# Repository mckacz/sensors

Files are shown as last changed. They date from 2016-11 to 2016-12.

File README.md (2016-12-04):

Simple wireless sensor system
=============================

As a part of home automation system for my house, I have designed a wireless sensors system that can continuously
monitor temperature, humidity, light and atmospheric pressure of multiple spots in the building.

This repository contains all elements required to build your own wireless sensor system based on ATmega328P, 
Raspberry PI and NRF24L01:

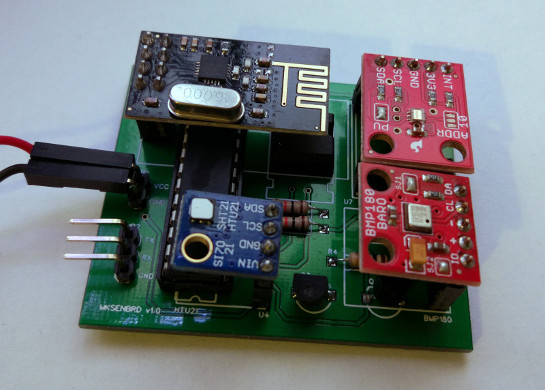
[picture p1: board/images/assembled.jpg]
Wireless sensor module


| Directory | Description |
|---|---|
| [board](./board) | Schematic and PCB design of wireless sensor module |
| [firmware](./firmware) | Arduino-compatible firmware for wireless sensor module |
| [example-server](./example-server) | Simple wireless sensors server for Raspberry PI | 

Case study
----------

As I mentioned, this wireless sensor system is a part of home automation system for my house.
At the moment, I have five wireless sensors connected to it. Each sensor module sends new readings in 16 seconds 
intervals and is powered by 3xAA rechargeable batteries - it is enough to power the module for over **2 months**. 
Power consumption is **~0.05 mA** in sleep mode and **20-30 mA** while measurements.  

**Cost of single module**

| Item | Price  | Note |
|---|---|---|
| PCB | $0.88  | ... if you order 20 PCB from EasyEDA (does not include shipping cost) |
| ATmega328P | $1.23* | |
| LD1117AV33 | $0.35* | |
| NRF24L01+ | $0.75* | |
| HTU21D | $2.40* | |
| TSL2561 | $1.50* | |
| BMP180 | $2.20* | |
| Other parts | $0.50* | Resistors, transistor, sockets |

Fully featured version: **$9.81**  
Temperature + humidity + light: **$7.61**  
Temperature + humidity: **$6.11**

Sums do not include cost of power supply. 

*) Prices from aliexpress.com (2016-12-04).

License
-------

[MIT](./LICENSE)

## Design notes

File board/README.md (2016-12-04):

Wireless sensor module board
============================

This directory contains schematic and PCB design for single wireless sensor module in [EAGLE](https://cadsoft.io/) 
format. Board design is also available on [EasyEDA](https://easyeda.com/maciej/sensors-387a7c4150d841bbb06d5350ea664e67).  

**Features**:
 * small dimensions - 55x45mm
 * low power consumption - ~40mA during measurement and ~40µA (0.04mA) in standby
 * supports standard BMP180, HTU21D and TSL2561 breakout boards - min. one is required, but all can be installed at same time 
 * input voltage from 3 to 5.5V 
 * low cost
 * open source [firmware](../firmware) 

Part list
---------

| PCB ID | Part name | Qty | Description |
|---|---|-----|---|
| U1 | ATmega328P (DIL28) |  1  | microcontroller |
| U2 | LD1117AV33 (TO220) |  1  | voltage regulator |
| U3 | NRF24L01+ |  1  | radio module |
| U4 | HTU21D (breakboard)  |  1  | temperature and humidity sensor | 
| U5/U6* | TSL2561 (breakboard) |  1  | luminescence sensor | 
| U7 | BMP180 (breakboard)  |  1  | barometer sensor |
| R1, R2 | resistor 10k |  2  | resistor |
| Q1 | BC337-40 |  1  | NPN transistor | 
| | pinhead 1x2 |  1  | pin header connector | 
| | pinhead 1x3 |  1  | pin header connector | 
| | pinhead 1x4 |  1  | pin header connector | 
| | pinhead 2x4 |  1  | pin header connector | 
| | pinhead 1x5 |  3  | pin header connector | 
| | DIL28 socket |  1  | socket for ATmega328P | 

*) There are two TSL2561 connectors (with different pin order) on the board, 
   but only one TSL2561 can be used at same time. 
 
Top layer
---------

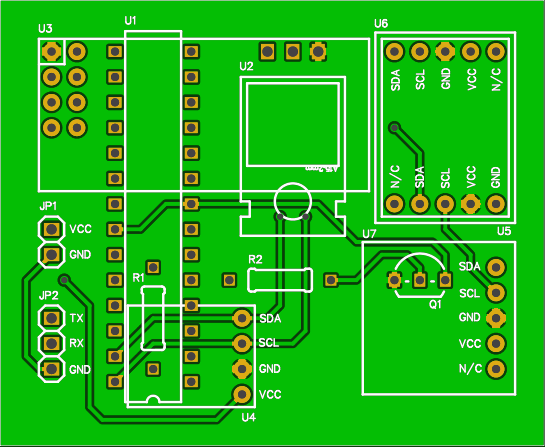
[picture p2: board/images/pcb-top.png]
Top layer


Bottom layer
------------

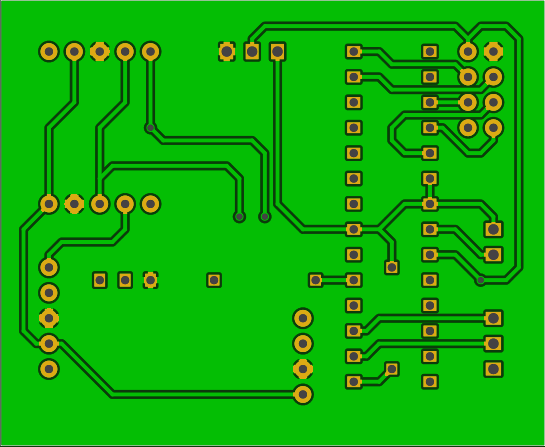
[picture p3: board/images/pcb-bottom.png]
Bottom layer


Assembled board
---------------

Wireless sensor module

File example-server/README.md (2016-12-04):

Example server
--------------

This is example of server that listens for readings send by wireless modules.

**Hardware requirements**

* Raspberry PI with enabled SPI
* NRF24L01+ radio module connected to Raspberry PI
* at least one [wireless sensor module](../board) with proper [firmware](../firmware)

**Software requirements**

* Python 3
* `spidev` package 
* [pyNRF](https://github.com/nettigo/pyNRF)
* [Tornado Web Server](http://www.tornadoweb.org/en/stable/)
* NodeJS and NPM to modify frontend JS files

**Running the example**
1. clone or download this repository
2. edit [`server.py`](./server.py) and set:
 * radio channel (same as option 1 in wireless module setup)
 * radio address (same as option 3 in wireless module setup)
 * your sensor names (key is sensor's ID from option I and value is name that will be displayed for the sensor)
  
3. run `python3 server.py` in `example-server` directory
4. open in a browser `http://your-raspberry-pi-ip:8000`

If everything works, you should see readings from your wireless sensors:
  
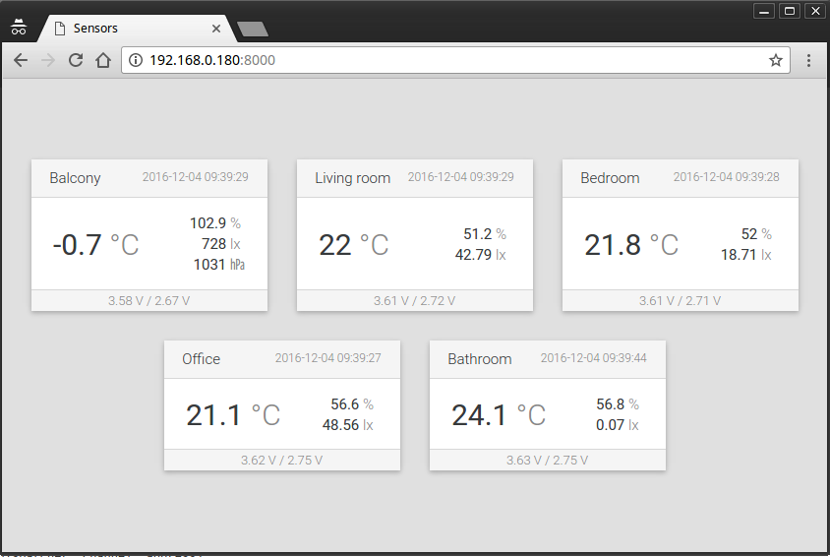
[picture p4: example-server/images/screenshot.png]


Readings on a web page will be updated (thought WebSocket) as soon as new reading will be received by the server.

**Modifying the example**

Example consists of:

* [`server.py`](./server.py) - main file of the server
* [`backand`](./backend) - classes used by the server
* [`frontend`](./frontend) - source JS files of frontend application compiled to `static/app.js` (ES6, React)
* [`static`](./static) - static files used by frontend application (HTML, CSS)

Everything except files in [`frontend`](./frontend) can be modified directly. [`frontend`](./frontend) contains 
ES6 and JSX files, so they must be compiled after modification.
 
Before first compilation, you must install dependencies with `npm install`, than you are able to run:

* `npm run build` to compile frontend files once
* `npm run watch` to continuously compile frontend files after each modification.

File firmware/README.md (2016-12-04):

Wireless sensor module firmware
===============================

**Features**:

* configurable through serial terminal
* optimized for power consumption (deep sleep mode)
* monitors actual voltage values
* compatible with ATmega328P @ 16MHz / 8MHz 
* easy to extend

Requirements
------------

* [Arduino IDE](https://www.arduino.cc/)
* [Sparkfun BMP180 library](https://github.com/sparkfun/BMP180_Breakout)
* [Sparkfun HTU21D library](https://github.com/sparkfun/SparkFun_HTU21D_Breakout_Arduino_Library)
* [Sparkfun TSL2561 library](https://github.com/sparkfun/SparkFun_TSL2561_Arduino_Library)
* "Minimal circuit" hardware configuration from [Arduino website](https://www.arduino.cc/en/Tutorial/ArduinoToBreadboard)*
* chip programmer* (like USBap)
* serial converter* (like USB TTL Serial)

*) Only if you are going to used it with provided PCB board

Installing on ATmega328p 
------------------------

1. prepare ATmega328p chip fused to run at 8Mhz internal oscillator
2. install required libraries through Arduino IDE's library manager 
3. compile and upload sketch to ATmega328p using your favourite chip programmer 
4. put programmed ATmega328p into socket on the board

Configuring the module
----------------------

1. power off the board
2. connect serial converter to JP2 connector on the board
3. setup and open serial connection 
  
  * boud rate: 19200
  * parity: none
  * bits: 8
  * stopbits: 1
  * flow control: none
  * immediate send characters 
  
4. power on the board
5. within next 5 seconds, press any key in serial terminal to enter setup mode

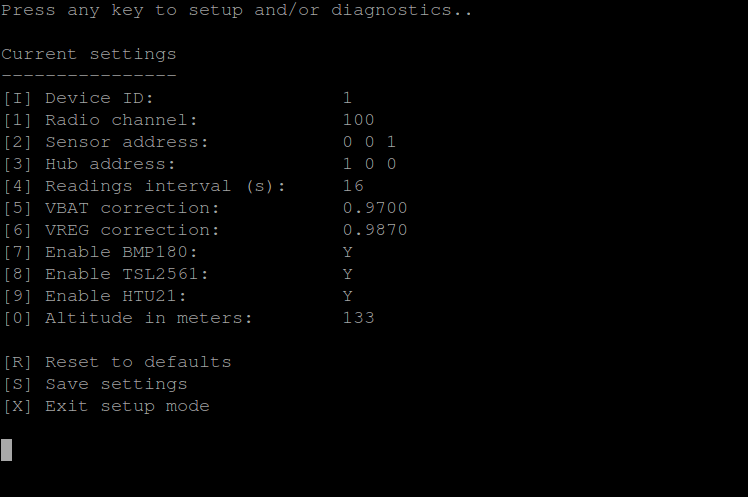
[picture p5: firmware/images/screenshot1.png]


**Available commands**

|  Key  | Description | Expected value | Note |
|---|---|---|---|
| **I** | Set Device ID. The ID will be send to the server with every message. | Integer (0-255) | Value should be unique for every module. |
| **1** | Set radio channel number to communicate with server. | Integer (1-125) | Value should be the same for every module and the server. |
| **2** | Set module radio address that NFR24L01 will use as a source address for each message. | 3x Integer (0-255) | Value should be unique for every module. |
| **3** | Set server radio address that NFR24L01 will use as a destination address for each message. | 3x Integer (0-255) | Value should be the same for every module. |
| **4** | Set reading interval in seconds. | Integer (1-255) | This affects most energy consumption. |
| **5** | Set input voltage reading correction factor. | Float | *factor = (voltage that you measure with multimeter on VCC @ JP1) / (voltage measured by module)*|
| **6** | Set regulated voltage reading correction factor. | Float | *factor = (voltage that you measure with multimeter on VCC @ U4) / (voltage measured by module)* |
| **7** | Enable/disable BMP180 | - | If you connect BMP180 to the module, set it to *Y* |
| **8** | Enable/disable TSL2561 | - | If you connect TSL2561 to the module, set it to *Y* |
| **9** | Enable/disable HTU21 | - | If you connect HTU21 to the module, set it to *Y* |
| **0** | Set altitude in meters (from sea level). | Integer (0-65535)  | Required if you connected BMP180. Use GPS to determine the altitude. |
| **R** | Reset settings to defaults. | | |
| **S** | Write settings to EEPROM. | | |
| **X** | Exit setup mode. | | |
 
First and each next digit of value that you entering must be entered within 5 seconds after previous one.
Each number can be ended/confirmed by any non-digit character (or you can wait 5 seconds). 
If selected command requires a few numbers, then separate them with any non-digit character.
Floating-point number can be entered as usual - with dot between digits. 

When you exit setup mode, the module will start its normal work cycle and will print on serial terminal current measurements.
When you power on the module and do not enter setup mode, serial terminal will be disabled.

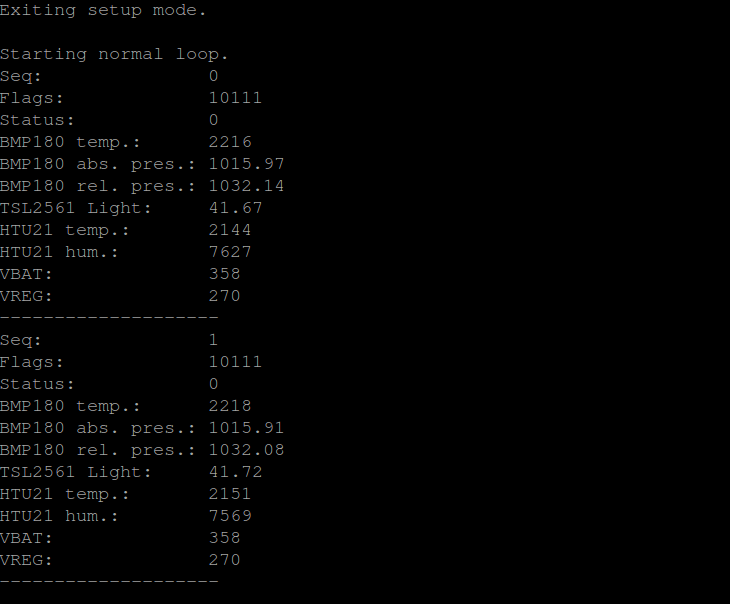
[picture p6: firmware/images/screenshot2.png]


Radio message format
--------------------

Communication between a module and a server is passive. Module only sends messages and server only receives messages.
Each message has the same format described by [`struct readings_t`](./sensors/sensors.h):

| Byte(s) | Type | Description |
|---|---|---|
|  0 | 8-bit unsigned integer  | Device ID |
|  1-2 | 16-bit unsigned integer | Subsequent message number |
|  3 | 8-bit unsigned integer  | Flags (described below) | 
|  4 | 8-bit unsigned integer  | Status (described below) | 
|  5-6 | 16-bit signed integer | Temperature in °C reported by BMP180 and multiplied by 100 (*1276* means *12.76 °C*) |
|  7-10 | 32-bit float | Absolute pressure in hPa reported by BMP180 |
|  11-14  | 32-bit float | Relative pressure in hPa reported by BMP180 |
|  15-18  | 32-bit float | Illumination in lux reported by TSL2561 |
|  19-20  | 16-bit signed integer | Temperature in °C reported by HTU21 and multiplied by 100 (*1276* means *12.76 °C*)  |
|  21-22  | 16-bit unsigned integer | Humidity in percent reported by HTU21 and multiplied by 100 (*6276* means *62.76 %*) |
|  23-24  | 16-bit unsigned integer | VCC voltage in V multiplied by 100 (*412* means *4.12 V*) |
|  25-26  | 16-bit unsigned integer | Regulated voltage in V multiplied by 100 (*272* means *2.72 V*) |

Flags
-----

| Bitmask | Constant name  | Description |
|---|---|---|
|  0x01 | ENABLE_BMP180  | Present if BMP180 is enabled for module.  |
|  0x02 | ENABLE_TSL2561 | Present if TSL2561 is enabled for module. | 
|  0x04 | ENABLE_HTU21 | Present if HTU21 is enabled for module. | 

Statuses
--------

| Bitmask | Constant name | Description |
|---|---|---|
|  0x00 | | Everything  fine - no error. |
|  0x01 | BAROMETER_ERR_INIT | BMP180 initialization error. |
|  0x02 | BAROMETER_ERR_TEMP_START  | BMP180 temperate measurement request error. | 
|  0x04 | BAROMETER_ERR_TEMP_READ | BMP180 temperate measurement error. | 
|  0x08 | BAROMETER_ERR_PRESS_START | BMP180 pressure measurement request error.  | 
|  0x10 | BAROMETER_ERR_PRESS_READ  | BMP180 pressure measurement error. | 
|  0x20 | LIGHT_ERR_READ | TSL2561 illumination measurement error. | 
|  0x30 | LIGHT_ERR_RANGE | TSL2561 measurement out of range. | 
|  0x40 | HUM_READ_ERR | HTU21 measurement error. |

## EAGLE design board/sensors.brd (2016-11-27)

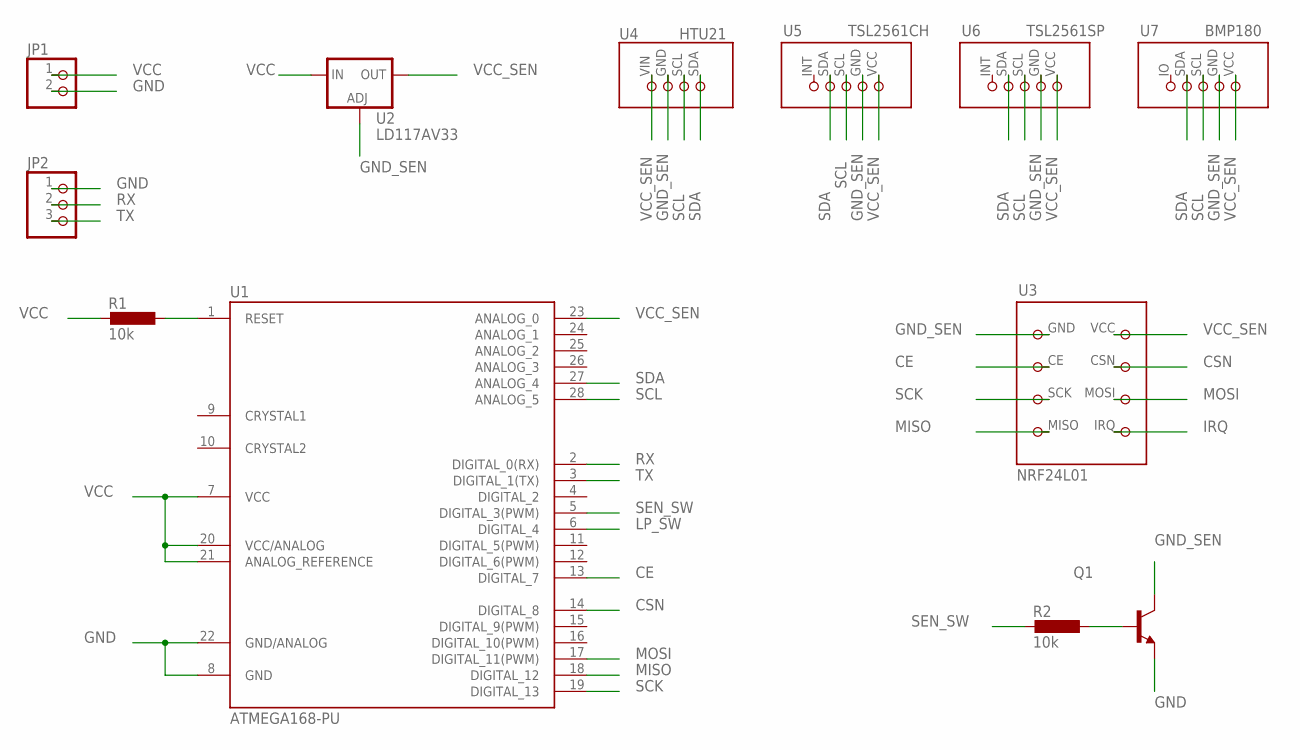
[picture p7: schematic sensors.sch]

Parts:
JP1: PINHD-1X2; 1X02
JP2: PINHD-1X3; 1X03
Q1: -NPN-TO92-EBC; TO92-EBC
R1, R2: 10k; 0207/10
U1: ATMEGA168-PU; DIL28-3
U2: LD117AV33; TO220L1
U3: NRF24L01
U4: HTU21
U5: TSL2561CH; TSL2561-CH
U6: TSL2561SP; TSL2561-SP
U7: BMP180

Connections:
CE: U1.13 (DIGITAL_7), U3.CE
CSN: U1.14 (DIGITAL_8), U3.CSN
GND: JP1.2, JP2.1, Q1.E, U1.8 (GND), U1.22 (GND/ANALOG)
GND_SEN: Q1.C, U2.1 (ADJ), U3.GND, U4.GND, U5.GND, U6.GND, U7.GND
IRQ: U3.IRQ
LP_SW: U1.6 (DIGITAL_4)
MISO: U1.18 (DIGITAL_12), U3.MISO
MOSI: U1.17 (DIGITAL_11(PWM)), U3.MOSI
unnamed: R1.1, U1.1 (RESET)
unnamed: Q1.B, R2.1
RX: JP2.2, U1.2 (DIGITAL_0(RX))
SCK: U1.19 (DIGITAL_13), U3.SCK
SCL: U1.28 (ANALOG_5), U4.SCL, U5.SCL, U6.SCL, U7.SCL
SDA: U1.27 (ANALOG_4), U4.SDA, U5.SDA, U6.SDA, U7.SDA
SEN_SW: R2.2, U1.5 (DIGITAL_3(PWM))
TX: JP2.3, U1.3 (DIGITAL_1(TX))
VCC: JP1.1, R1.2, U1.7 (VCC), U1.20 (VCC/ANALOG), U1.21 (ANALOG_REFERENCE), U2.3 (IN)
VCC_SEN: U1.23 (ANALOG_0), U2.2 (OUT), U3.VCC, U4.VIN, U5.VCC, U6.VCC, U7.VCC

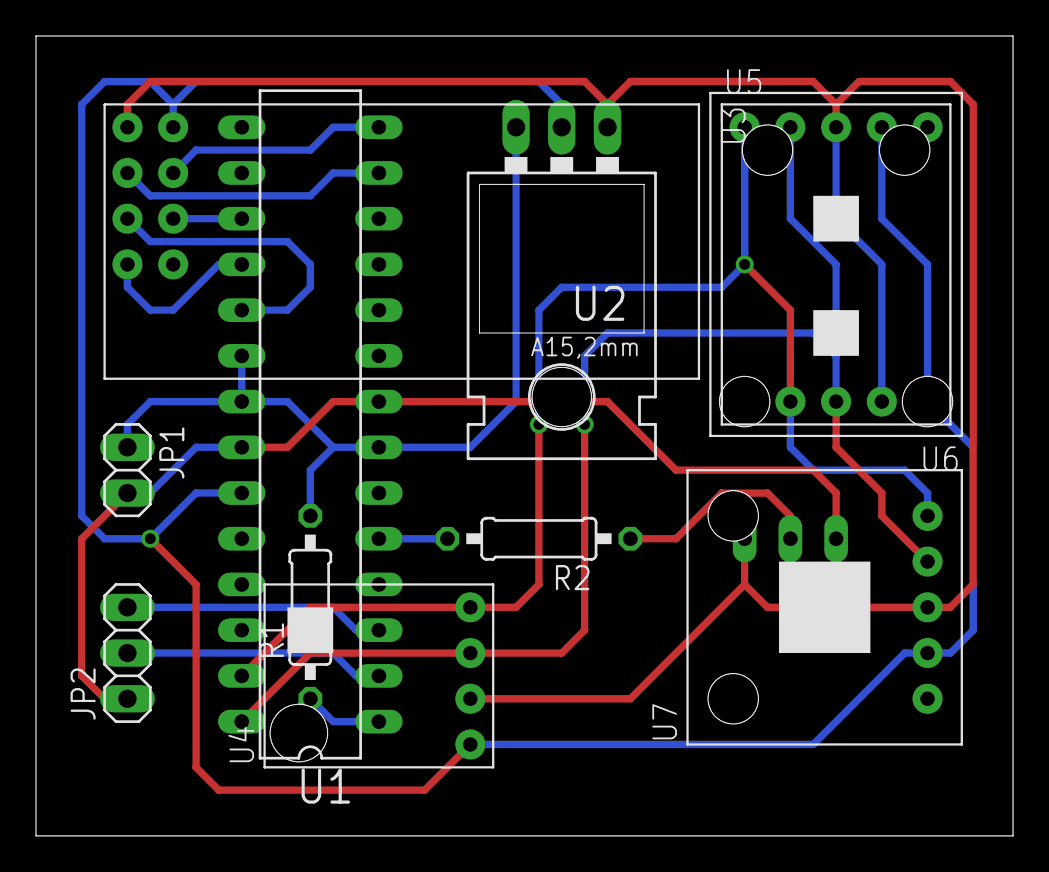
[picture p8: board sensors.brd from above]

Board: 2 copper layers, 54.3 x 44.4 mm, 12 parts (1 on the bottom side), 16 nets.

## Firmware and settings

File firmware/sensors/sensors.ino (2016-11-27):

#include <Wire.h>
#include <SPI.h>

#include "sensors.h"
#include "barometer.h"
#include "light.h"
#include "htu.h"
#include "vcc.h"
#include "ui.h"
#include "lib/power.h"
#include "lib/radio.h"

options_t options;

Vcc vcc;
readings_t readings;

void vcc_read();
void reset_readings();

void setup() {
    //power up sensors
    pinMode(PIN_POWER, OUTPUT);
    digitalWrite(PIN_POWER, HIGH);

    //read or setup options
    ui_setup(options);

    //initialize enabled sensors
    if(options.flags & ENABLE_BMP180) {
        barometer_begin();
    }

    if(options.flags & ENABLE_TSL2561) {
        light_begin();
    }

    if(options.flags & ENABLE_HTU21) {
        htu_begin();
    }

    //set common reading values
    readings.id = options.id;
    readings.seq = 0;
    readings.flags = options.flags;
}

void loop() {
    reset_readings();

    //power up sensors and radio
    digitalWrite(PIN_POWER, HIGH);
    digitalWrite(PIN_RADIO_CSN, HIGH);

    //wait for power to settle
    delay(500);

    //read voltages
    vcc_read();

    //read values from enabled sensors
    if(options.flags & ENABLE_BMP180) {
        barometer_read(readings, options);
    }

    if(options.flags & ENABLE_TSL2561) {
        light_read(readings);
    }

    if(options.flags & ENABLE_HTU21) {
        htu_read(readings);
    }

    //send whose struct through radio
    Radio.begin(options.sen_addr, options.channel, PIN_RADIO_CSN, PIN_RADIO_CE);
    Radio.write(options.hub_addr, readings);
    Radio.flush();

    //power off radio (software)
    Radio.off();
    SPI.end();

    //manually reset SPI and radio pins to input
    //without this, radio will drain battery and hang Arduino after switching power off in next step.
    pinMode(MOSI, INPUT);
    pinMode(MISO, INPUT);
    pinMode(SCK, INPUT);
    pinMode(PIN_RADIO_CE, INPUT);
    pinMode(PIN_RADIO_CSN, INPUT);

    //power off sensors and radio
    digitalWrite(PIN_POWER, LOW);

    //print reading if diagnostinc mode is enabled
    ui_loop(readings);

    //increment sequence number
    readings.seq++;

    //deep sleep
    sleep(1000 * options.interval);
}

void reset_readings() {
    readings.status = 0;
    readings.bar_temp = 0;
    readings.bar_pres_abs = 0;
    readings.bar_pres_rel = 0;
    readings.htu_temp = 0;
    readings.htu_hum = 0;
    readings.vbat = 0;
    readings.vreg = 0;
}

void vcc_read() {
    readings.vbat = vcc.Read_Volts() * 100.0 * options.vbat_correct;
    readings.vreg = (analogRead(A0) / 1024.0) * readings.vbat * options.vreg_correct;
}

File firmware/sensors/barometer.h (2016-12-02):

#ifndef __BAROMETER_H
#define __BAROMETER_H

#include "sensors.h"

#define BAROMETER_ERR_INIT        1
#define BAROMETER_ERR_TEMP_START  2
#define BAROMETER_ERR_TEMP_READ   4
#define BAROMETER_ERR_PRESS_START 8
#define BAROMETER_ERR_PRESS_READ  16

extern void barometer_begin();
extern void barometer_read(readings_t &readings, options_t &options);

#endif

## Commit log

2016-11-27 Import to Git
    [sensors.brd, sensors.sch]
2016-12-01 Board and Firmare READMEs
